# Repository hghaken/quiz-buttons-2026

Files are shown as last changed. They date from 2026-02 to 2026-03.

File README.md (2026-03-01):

# Quiz Buttons 2026

A wireless quiz buzzer system built with **ESP32-S3** hardware buttons and a **Raspberry Pi** web-based game controller.
Players press physical buttons to buzz in; the server tracks press order, manages scores, rounds, jokers, and runs a live web dashboard for the quizmaster.

---

## Table of Contents

- [System Overview](#system-overview)
- [Hardware](#hardware)
  - [Components](#components)
  - [Wiring](#wiring)
- [Software Architecture](#software-architecture)
- [Raspberry Pi Setup](#raspberry-pi-setup)
  - [Dependencies](#dependencies)
  - [Running as a Service](#running-as-a-service)
- [ESP32 Firmware](#esp32-firmware)
  - [PlatformIO Build](#platformio-build)
  - [Configuration](#configuration)
  - [OTA Firmware Updates](#ota-firmware-updates)
- [Network Setup](#network-setup)
- [Game Flow](#game-flow)
- [LED Color Reference](#led-color-reference)
- [Buzzer Patterns](#buzzer-patterns)
- [MQTT Topics](#mqtt-topics)
- [Web Interface](#web-interface)
  - [Results Page](#results-page-http1922)
  - [Score Overview](#score-overview-http1922score)
  - [Setup Page](#setup-page-http1922setup)
- [File Structure](#file-structure)
- [Versioning](#versioning)

---

## System Overview

```
┌─────────────────────────────────────────────────────┐
│              Wi-Fi Network (192.168.0.x)            │
│                                                     │
│  ┌─────────────┐   MQTT    ┌─────────────────────┐  │
│  │  ESP32-S3   │◄─────────►│  Raspberry Pi 4B    │  │
│  │  Button #1  │           │  - Mosquitto MQTT   │  │
│  └─────────────┘           │  - Flask Web Server │  │
│  ┌─────────────┐   MQTT    │  - Python Controller│  │
│  │  ESP32-S3   │◄─────────►│                     │  │
│  │  Button #2  │           │  Port 5000 (HTTP)   │  │
│  └─────────────┘           └──────────┬──────────┘  │
│        ...                            │             │
└───────────────────────────────────────┼─────────────┘
                                        │
                              ┌─────────▼──────────┐
                              │  Quizmaster Browser │
                              │  (any device on LAN)│
                              └────────────────────┘
```

Each ESP32-S3 button connects to the Raspberry Pi via **MQTT** over Wi-Fi.
The Pi runs a **Flask** web server that the quizmaster uses to manage the game.

---

## Hardware

### Components

| Component | Part | Notes |
|---|---|---|
| Microcontroller | Seeed XIAO ESP32-S3 | One per player |
| Button | Momentary push button | Connects D0 (GPIO1) to GND |
| Buzzer | Active buzzer or piezo | Connects D1 (GPIO2) to GND |
| Status LED | Single LED | D2 (GPIO3), MQTT connection indicator |
| RGB LED | Common cathode RGB LED | D8/D9/D10 (GPIO7/8/9) |
| Battery | 3.7V 10000mAh 1260110 Li-ion Polymer Battery | Rechargeable LiPo, one per button |
| Charger / Boost | LX-LCBST TP4056 Module | Li-ion charger + DC-DC step-up boost (3.7V → 5V for ESP32) |
| Server | Raspberry Pi 4B | Runs MQTT broker + Flask |
| Buzzer (Pi) | Active buzzer | GPIO17, confirms quizmaster actions |

### Wiring

#### ESP32-S3 (Seeed XIAO ESP32-S3)

| Pin | GPIO | Function | Resistor |
|---|---|---|---|
| D0 | GPIO 1 | Button (INPUT_PULLUP → GND) | — |
| D1 | GPIO 2 | Active buzzer (→ GND) | 47 Ω |
| D2 | GPIO 3 | Status LED (solid = MQTT connected, flash = disconnected) | 47 Ω |
| D8 | GPIO 7 | RED LED (PWM) | 100 Ω |
| D9 | GPIO 8 | GREEN LED (PWM) | 47 Ω |
| D10 | GPIO 9 | BLUE LED (PWM) | 47 Ω |

#### Raspberry Pi 4B

| GPIO | Function |
|---|---|
| GPIO 17 | Active buzzer (quizmaster feedback) |

### 3D Printed Enclosure

The button housing is designed in **FreeCAD** and printed in 5 parts.
Source and print files are in the [`3D Printer Files/`](3D%20Printer%20Files/) folder.

| File | Description |
|---|---|
| `QuizButton2026.FCStd` | FreeCAD source file (full assembly) |
| `QuizButton2026-PartQB2026MainV3.3mf` | Main body |
| `QuizButton2026-PartQB2026Top.3mf` | Top cover |
| `QuizButton2026-PartQB2026Bottom.3mf` | Bottom plate |
| `QuizButton2026-PartQB2026AccuBracket.3mf` | Battery bracket |
| `QuizButton2026-PartQB2026AccuSupport.3mf` | Battery support |

### ESP32 Power Supply

Each button unit is powered by a LiPo battery with an integrated charger and boost converter:

| Part | Description |
|---|---|
| 3.7V 10000mAh 1260110 Li-ion Polymer Battery | Rechargeable LiPo battery |
| LX-LCBST TP4056 Module | Li-ion charger + DC-DC step-up boost converter (charges via USB, boosts 3.7V → 5V for ESP32) |

#### Battery Life Estimate

| Scenario | Draw | Estimated Runtime |
|---|---|---|
| Peak (WiFi TX bursts) | 125 mA | ~68 hours |
| Average (WiFi idle) | ~70 mA | ~120 hours (~5 days) |

Assumptions: boost converter efficiency 85–90% → usable capacity ≈ 8,500 mAh; LiPo discharged to 3.0V cutoff.
For a typical quiz evening of a few hours, the 10,000 mAh battery will last **dozens of sessions** between charges.

---

## Software Architecture

```
raspberry_pi/
├── server.py                  # Flask + MQTT controller (main application)
├── config.json                # Timeout, rounds, questions per round
├── player_names.json          # Button ID → player/team name mapping
├── scores.json                # Per-round scores per player
├── correct_answers.json       # Correct answer count per round per player
├── jokers.json                # Joker usage per player
├── current_round.json         # Persisted current round number
├── round_descriptions.json    # Round descriptions (e.g. "Music Round")
├── static/
│   └── style.css
└── templates/
    ├── results.html           # Main quizmaster dashboard (auto-refreshes)
    ├── score.html             # Score overview with chart
    ├── setup.html             # Game configuration + OTA
    └── restart.html           # Shown during server restart

src/
└── main.cpp                   # ESP32-S3 Arduino firmware (PlatformIO)

platformio.ini                 # PlatformIO build configuration
```

---

## Raspberry Pi Setup

### Dependencies

```bash
sudo apt update && sudo apt install -y mosquitto mosquitto-clients python3-pip python3-venv

# Create virtual environment
python3 -m venv /home/game/quiz/env
source /home/game/quiz/env/bin/activate

pip install flask paho-mqtt gpiozero matplotlib
```

### Deploy Files

```bash
# Copy project files to Pi
scp -P 2222 -r raspberry_pi/* game@<pi-ip>:/home/game/quiz/
```

### Running as a Service

Create `/etc/systemd/system/quiz.service`:

```ini
[Unit]
Description=Quiz Server
After=network.target mosquitto.service

[Service]
User=game
WorkingDirectory=/home/game/quiz
ExecStart=/home/game/quiz/env/bin/python3 /home/game/quiz/server.py
Restart=on-failure

[Install]
WantedBy=multi-user.target
```

```bash
sudo systemctl enable quiz
sudo systemctl start quiz
sudo systemctl status quiz
```

### Mosquitto MQTT Broker

The MQTT broker runs locally on the Pi on port `1883`.
The ESP32 buttons connect using credentials:

```
Username: quizuser
Password: quizpass
```

Configure `/etc/mosquitto/mosquitto.conf` to allow these credentials.

---

## ESP32 Firmware

### PlatformIO Build

```bash
# Install PlatformIO (VS Code extension or CLI)
pio run                        # Build
pio run --target upload        # Flash via USB (COM4)
```

Board: `seeed_xiao_esp32s3`
Framework: Arduino
Library: `knolleary/PubSubClient@^2.8`

### Configuration

Edit the constants at the top of [src/main.cpp](src/main.cpp):

```cpp
const char* version    = "v0.13 (01-03-2026)";
const char* ssid       = "your-wifi-ssid";
const char* password   = "your-wifi-password";
const char* mqttServer = "192.168.0.10";   // Raspberry Pi IP
const int   mqttPort   = 1883;
const char* mqttUser   = "quizuser";
const char* mqttPass   = "quizpass";
```

### OTA Firmware Updates

The ESP32 supports **HTTP pull-based OTA** — the device downloads firmware from the Pi's Flask server when triggered via MQTT.

**Process:**
1. Build the firmware: `pio run`
2. Copy `.pio/build/seeed_xiao_esp32s3/firmware.bin` to the project
3. Upload via the Setup page → **"Uploaden naar Pi"**
4. Click **"OTA Update — Alle Knoppen"** (all buttons) or per-button OTA
5. Buttons turn **purple** (downloading) → **green** (done) → reboot

The firmware binary is served at `http://<pi-ip>:5000/firmware.bin`.

---

## Network Setup

| Device | IP Address | Notes |
|---|---|---|
| Raspberry Pi 4B | `192.168.0.10` | MQTT broker + Flask server |
| ESP32 Buttons | `192.168.0.x` | DHCP, same subnet as Pi |
| Quizmaster PC | `10.10.8.x` | Different subnet, accesses Pi via port 5000 |

> The ESP32 buttons are on a dedicated `192.168.0.0/24` network. OTA uses HTTP pull from the Pi so the buttons can reach the server even when the quizmaster's PC cannot directly reach the buttons.

---

## Game Flow

```
Server start → Round 1, Question 1
     │
     ▼
[Joker phase] ← Only at round start, before first question
     │           Each player may use their joker once (doubles points for that round)
     ▼
"Start Vraag" (Blue button) → All buttons ENABLED (green LED)
     │
     ▼
Players press buttons → Press order recorded
     │                   Rank colors assigned (Blue=1st, Purple=2nd, Yellow=3rd, White=rest)
     ▼
Countdown timer starts (configurable, default 30s)
     │
     ▼
1st player answers:
  ├── Correct → Award 1/2/3 points → "Volgende Vraag" / "Volgende Ronde"
  └── Wrong   → "Fout (Blokeren)" → 2nd player answers → ...
                                          └── All wrong → "Reset Ronde (geen punten)"
                                                          (wrong-answer buttons stay red,
                                                           unanswered buttons re-enabled)
     │
     ▼
After all questions in round → "Volgende Ronde" (cyan button)
     │
     ▼
After all rounds → "Quiz compleet!"
```

---

## LED Color Reference

### RGB LED (game state)

| Color | Meaning |
|---|---|
| Green | Button enabled / waiting for question |
| Red | Button disabled / locked |
| Blue | Rank 1 (buzzed in first) |
| Purple | Rank 2 (buzzed in second) |
| Yellow | Rank 3 (buzzed in third) |
| White | Rank 4+ (buzzed in but not top 3) |
| Purple | OTA firmware downloading |

**Startup sequence:**
Green (init) → Red (WiFi connected) → White (NTP synced) → Blue (MQTT ready) + 1s beep

### Status LED (D2 / GPIO3)

| State | Meaning |
|---|---|
| Solid ON | MQTT connected |
| Flashing (500ms) | MQTT disconnected, retrying every 5 s |

---

## Buzzer Patterns

| Pattern | Beeps | Trigger |
|---|---|---|
| PAT_ANSWER | 1 beep (200ms) | Your buzz acknowledged |
| PAT_RESET | 2 beeps (150ms each) | Round reset / button unlocked |
| PAT_DISABLE | 3 beeps (130ms each) | Button locked / disabled |

---

## MQTT Topics

| Topic | Direction | Payload | Description |
|---|---|---|---|
| `quiz/all` | Pi → Buttons | `enable`, `disable`, `lock`, `unlock`, `reset`, `reregister`, `ota`, `brightness:R,G,B` | Broadcast command to all buttons |
| `quiz/<id>` | Pi → Button | `enable`, `disable`, `buzz`, `rank:1`…`rank:4`, `ota` | Command to specific button |
| `quiz/register` | Button → Pi | `<button-id>` | Button announces itself on connect |
| `quiz/version` | Button → Pi | `<id>,<version>,<ip>` | Firmware version + IP report |
| `quiz/press` | Button → Pi | `<id>,<timestamp-ms>` | Button press event |
| `quiz/heartbeat` | Button → Pi | `<button-id>` | Keep-alive every 5 seconds |
| `quiz/offline` | Button → Pi (LWT) | `<button-id>` | Last-will message on disconnect |

Button IDs are the ESP32 MAC address formatted as a 16-character uppercase hex string.

---

## Web Interface

### Results Page (`http://<pi-ip>:5000/`)

The main quizmaster dashboard. Auto-refreshes every 2 seconds.

- Shows all registered buttons sorted by name (then by press order during a question)
- Displays press rank, speed (ms relative to first press), status, score, correct answers, joker
- Buttons: Start Question, Next Question, Next Round, Award Points (1/2/3), Block Wrong Answer, Reset Round, Reset Scores, Find All Buttons
- Countdown timer during answer phase

### Score Overview (`http://<pi-ip>:5000/score`)

- Sortable score table with per-round breakdown (points + correct answers)
- Cumulative score graph per round (matplotlib PNG)
- Joker usage shown per player

### Setup Page (`http://<pi-ip>:5000/setup`)

| Section | Setting |
|---|---|
| 1 | Answer timeout in seconds (0 = disabled) |
| 2 | Total number of rounds |
| 3 | Number of questions per round |
| 4 | Round descriptions (e.g. "Music Round", "General Knowledge") |
| 5 | Player / team names and display colors per button |
| 6 | RGB LED brightness (separate R/G/B sliders, 0–255) |
| 7 | OTA firmware update (upload .bin + trigger update per button or all) |

Also: Restart server, Shutdown Pi, software version display.

---

## File Structure

```
Quiz Buttons 2026/
├── 3D Printer Files/
│   ├── QuizButton2026.FCStd      # FreeCAD source (full assembly)
│   ├── QuizButton2026-PartQB2026MainV3.3mf
│   ├── QuizButton2026-PartQB2026Top.3mf
│   ├── QuizButton2026-PartQB2026Bottom.3mf
│   ├── QuizButton2026-PartQB2026AccuBracket.3mf
│   └── QuizButton2026-PartQB2026AccuSupport.3mf
├── src/
│   └── main.cpp                  # ESP32-S3 Arduino firmware
├── raspberry_pi/
│   ├── server.py                 # Flask + MQTT quiz controller
│   ├── config.json               # Game settings
│   ├── player_names.json         # Button → name mapping
│   ├── player_colors.json        # Button → display color mapping
│   ├── scores.json               # Score data
│   ├── correct_answers.json      # Correct answer counts
│   ├── jokers.json               # Joker usage
│   ├── current_round.json        # Current round state
│   ├── round_descriptions.json   # Round labels
│   ├── led_brightness.json       # RGB LED brightness per channel
│   ├── static/
│   │   └── style.css
│   └── templates/
│       ├── results.html
│       ├── score.html
│       ├── setup.html
│       └── restart.html
├── platformio.ini                # PlatformIO config (seeed_xiao_esp32s3)
├── ...AI Info/
│   ├── Game rules.txt            # Game rules and flow description
│   └── OTA Upload Info.txt       # OTA setup notes
└── README.md
```

---

## Versioning

| Component | Version | File |
|---|---|---|
| ESP32 Firmware | v0.13 (01-03-2026) | `src/main.cpp` |
| Quiz Server | v1.0.5 (01-03-2026) | `raspberry_pi/server.py` |

Server version is displayed in the bottom-right corner of the Setup page.
Per-button firmware version is reported via MQTT on connect and shown in the OTA table on the Setup page.

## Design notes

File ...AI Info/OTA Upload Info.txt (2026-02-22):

When you update the firmware:

1 - Make code changes in VS Code

2 - Build: pio run (or press the PlatformIO build button) (check icon in bottom)
    generates: .pio/build/seeed_xiao_esp32s3/firmware.bin

3 - Go to the Setup page → section 5. OTA Firmware Update

4 - Click "Selecteer firmware .bin bestand" → browse to
    .pio/build/seeed_xiao_esp32s3/firmware.bin

5 - Click "Uploaden naar Pi" — uploads the binary to the Pi
    /home/game/quiz/firmware.bin

6 - Click "OTA Update — Alle Knoppen" — Pi sends MQTT ota to all buttons

7 - Buttons turn purple (downloading), then green (done) and reboot automatically

No USB cable, no IP addresses to remember, no terminal commands needed.

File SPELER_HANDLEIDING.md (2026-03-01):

# Quiz Knop — Speler Handleiding

---

## Jouw knop

Elke speler heeft een draadloze quiz-knop met:

- Een grote **drukknop** bovenop
- Een **RGB LED** die aangeeft wat de status van jouw knop is
- Een **zoemer** die geluid geeft bij belangrijke momenten
- Een **oplaadbare batterij** (USB-C aansluiting)

---

## LED Kleuren

De kleur van het lampje vertelt je precies wat er aan de hand is.

| Kleur | Betekenis |
|---|---|
| 🟢 **Groen** | Knop is actief — je kunt buzzen! |
| 🔴 **Rood** | Knop is uitgeschakeld — wachten |
| 🔵 **Blauw** | Jij was de **eerste** die drukte |
| 🟣 **Paars** | Jij was de **tweede** die drukte |
| 🟡 **Geel** | Jij was de **derde** die drukte |
| ⚪ **Wit** | Jij drukte ook, maar later (4e of verder) |

> **Tip:** Hoe eerder je drukt, hoe eerder je mag antwoorden!

---

## Zoemer Signalen

De zoemer in de knop geeft je feedback:

| Signaal | Betekenis |
|---|---|
| **1 korte piep** | Je buzz is geregistreerd |
| **2 piepen** | De ronde is gereset — knop weer actief |
| **3 piepen** | Jouw knop is uitgeschakeld (fout antwoord) |

---

## Hoe werkt het spel?

### Stap 1 — Wachten op de vraag
De quizmaster stelt de vraag. Jouw LED is **rood** — nog niet drukken.

### Stap 2 — Knop groen!
Zodra de LED **groen** wordt, mag je buzzen. Weet je het antwoord? **Druk de knop!**

### Stap 3 — Buzz geregistreerd
Je hoort **1 piep** en je LED toont jouw rangkleur:
- Blauw = jij was 1e, Paars = 2e, Geel = 3e, Wit = 4e of later

### Stap 4 — Antwoorden
De **eerste** speler (blauwe LED) geeft het antwoord.

**Antwoord goed?** → De quizmaster geeft punten. De ronde is klaar.

**Antwoord fout?** → Jouw knop wordt rood (3 piepen). De **volgende** speler in de rij mag antwoorden.

### Stap 5 — Niemand weet het
Als niemand het goed heeft, resettet de quizmaster de ronde. Je hoort **2 piepen** en je LED wordt weer groen — alle knoppen gaan een nieuwe vraag in.

> **Let op:** Spelers met een fout antwoord blijven rood — zij mogen bij de volgende vraag gewoon weer meedoen.

---

## Punten

De quizmaster kent punten toe: **1**, **2** of **3** punten per vraag.
Hoeveel punten je krijgt hangt af van de moeilijkheid van de vraag.

Jouw score is live te zien op het scorebord.

---

## De Joker 🃏

Elke speler heeft **één joker** voor het hele spel.

- De joker verdubbelt al jouw punten voor een **hele ronde**
- Je kunt de joker alleen inzetten **vóór de eerste vraag** van een ronde
- Gebruik hem slim — wanneer jij denkt dat je het goed doet!

> **Voorbeeld:** Je joker inzetten in de muziekronde als je veel van muziek weet = extra beloning voor elk goed antwoord in die ronde.

---

## Opstarten

Wanneer de knop wordt aangezet doorloopt hij een korte reeks:

| LED kleur | Wat er gebeurt |
|---|---|
| 🟢 Groen | Knop start op |
| 🔴 Rood | Verbinding met WiFi gemaakt |
| ⚪ Wit | Tijd wordt gesynchroniseerd |
| 🔵 Blauw + lange piep | Verbonden met de quiz server — klaar! |

De knop staat klaar zodra je de lange piep hoort.

---

## Tips

- **Druk alleen als je het antwoord weet** — een fout antwoord blokkeert jou en geeft anderen de kans.
- **Wacht op groen** — te vroeg drukken werkt niet (knop is nog rood).
- **Joker op het juiste moment** — gebruik hem in de ronde waar jij het sterkst bent.
- **Knop valt uit?** Vraag de quizmaster om "Alle knoppen zoeken" te klikken. Jouw knop meldt zich vanzelf opnieuw aan.

---

## Opladen

- Laad de knop op via de **USB-C** aansluiting.
- De batterij is groot genoeg voor meerdere speelrondes — maar laad op na gebruik.
- Laad **niet** op terwijl de knop in het spel is.

---

*Veel plezier en veel succes!* 🎉

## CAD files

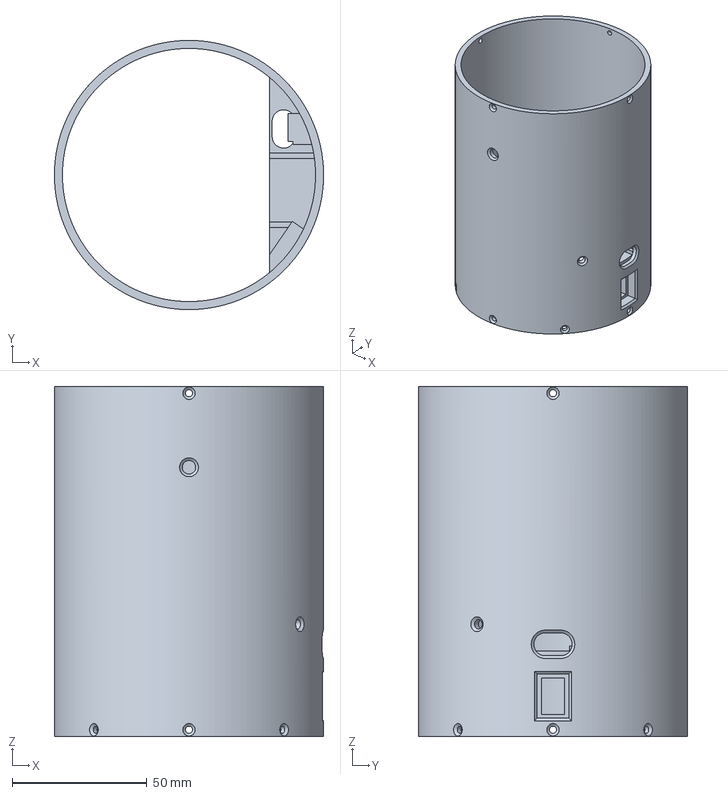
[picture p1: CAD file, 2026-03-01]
3D Printer Files/QuizButton2026-PartQB2026MainV3.3mf
100.0 x 100.0 x 130.0 mm

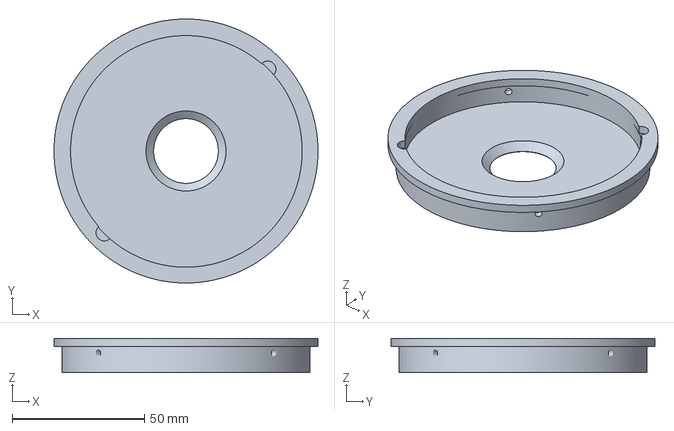
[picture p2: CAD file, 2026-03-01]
3D Printer Files/QuizButton2026-PartQB2026Top.3mf
100.0 x 100.0 x 13.0 mm

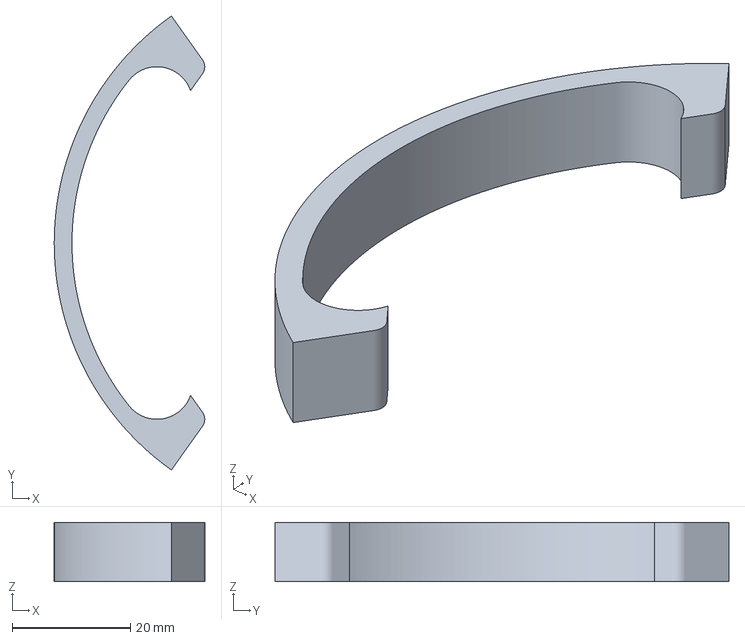
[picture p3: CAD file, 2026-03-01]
3D Printer Files/QuizButton2026-PartQB2026AccuBracket.3mf
25.4 x 76.6 x 10.0 mm

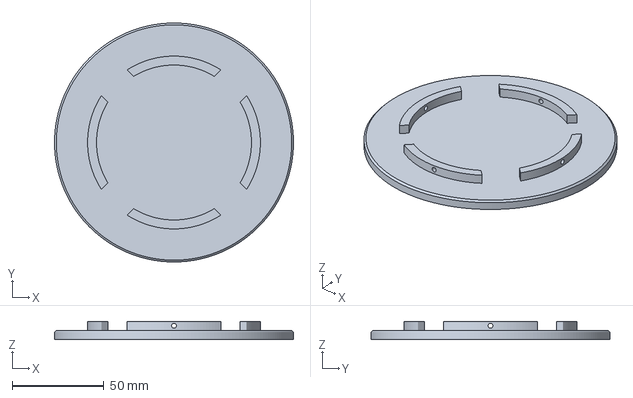
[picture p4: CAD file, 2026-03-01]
3D Printer Files/QuizButton2026-PartQB2026Bottom.3mf
130.0 x 130.0 x 9.80 mm

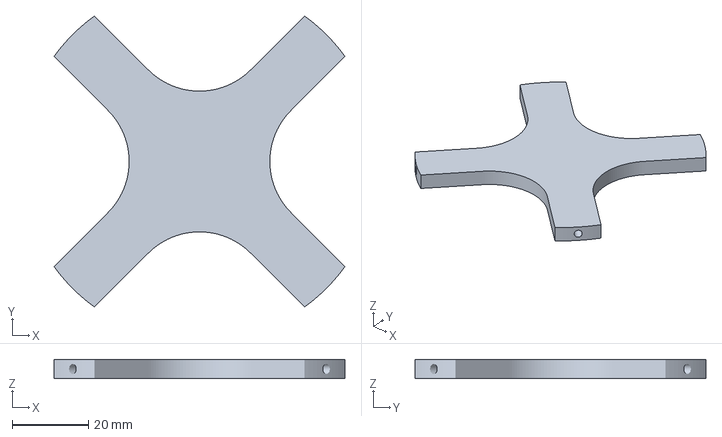
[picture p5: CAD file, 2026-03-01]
3D Printer Files/QuizButton2026-PartQB2026AccuSupport.3mf
76.2 x 76.2 x 5.00 mm

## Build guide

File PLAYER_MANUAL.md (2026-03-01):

# Quiz Button — Player Manual

---

## Your Button

Every player has a wireless quiz button with:

- A large **push button** on top
- An **RGB LED** that shows the status of your button
- A **buzzer** that gives audio feedback at key moments
- A **rechargeable battery** (USB-C connector)

---

## LED Colors

The color of the LED tells you exactly what is happening.

| Color | Meaning |
|---|---|
| 🟢 **Green** | Button is active — you can buzz! |
| 🔴 **Red** | Button is disabled — wait |
| 🔵 **Blue** | You were the **first** to press |
| 🟣 **Purple** | You were the **second** to press |
| 🟡 **Yellow** | You were the **third** to press |
| ⚪ **White** | You pressed too, but later (4th or beyond) |

> **Tip:** The earlier you press, the earlier you get to answer!

---

## Buzzer Signals

The buzzer inside the button gives you audio feedback:

| Signal | Meaning |
|---|---|
| **1 short beep** | Your buzz has been registered |
| **2 beeps** | The round was reset — button is active again |
| **3 beeps** | Your button has been disabled (wrong answer) |

---

## How Does the Game Work?

### Step 1 — Wait for the question
The quizmaster reads the question. Your LED is **red** — do not press yet.

### Step 2 — Button turns green!
As soon as the LED turns **green**, you may buzz in. Know the answer? **Press the button!**

### Step 3 — Buzz registered
You hear **1 beep** and your LED shows your rank color:
- Blue = you were 1st, Purple = 2nd, Yellow = 3rd, White = 4th or later

### Step 4 — Answer the question
The **first** player (blue LED) gives their answer.

**Answer correct?** → The quizmaster awards points. The question is done.

**Answer wrong?** → Your button turns red (3 beeps). The **next** player in line gets to answer.

### Step 5 — Nobody knows it
If nobody answers correctly, the quizmaster resets the round. You hear **2 beeps** and your LED turns green again — all buttons are ready for the next question.

> **Note:** Players who gave a wrong answer stay red for that question, but can buzz in again on the next question.

---

## Points

The quizmaster awards **1**, **2** or **3** points per question.
The number of points depends on the difficulty of the question.

Your score is shown live on the scoreboard.

---

## The Joker 🃏

Every player has **one joker** for the entire game.

- The joker **doubles all your points** for an entire round
- You can only use the joker **before the first question** of a round
- Use it wisely — pick the round where you think you will score best!

> **Example:** Using your joker in the music round when you know a lot about music = extra reward for every correct answer in that round.

---

## Startup Sequence

When the button is switched on it runs through a short sequence:

| LED Color | What is happening |
|---|---|
| 🟢 Green | Button is starting up |
| 🔴 Red | Connected to WiFi |
| ⚪ White | Time is being synchronized |
| 🔵 Blue + long beep | Connected to the quiz server — ready! |

The button is ready to use as soon as you hear the long beep.

---

## Tips

- **Only press if you know the answer** — a wrong answer blocks you and gives others a chance.
- **Wait for green** — pressing too early does nothing (button is still red).
- **Joker timing matters** — use it in the round where you are strongest.
- **Button disconnected?** Ask the quizmaster to click "Find all buttons". Your button will automatically reconnect.

---

## Charging

- Charge the button using the **USB-C** connector.
- The battery is large enough for multiple game sessions — but charge it after use.
- Do **not** charge while the button is actively in a game.

---

*Good luck and have fun!* 🎉

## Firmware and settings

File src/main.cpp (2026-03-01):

// RGB LED states:
// setup():
//   GREEN   – Initialising
//   RED     – WiFi connected
//   WHITE   – NTP time synced
//   BLUE    – MQTT connected and ready  + long buzz
// loop():
//   GREEN   – Button enabled / unlocked
//   RED     – Button disabled / locked
//   BLUE    – Rank 1 (winner)
//   PURPLE  – Rank 2  (180,0,180 – distinct from OTA violet 128,0,255)
//   YELLOW  – Rank 3
//   WHITE   – Rank 4+
//   PURPLE  – OTA firmware downloading
//   GREEN   – OTA done → reboot
//   RED     – OTA error
//
// Status LED (D2):
//   ON      – MQTT connected
//   FLASH   – MQTT disconnected (retrying every 5 s)

#include <Arduino.h>
#include <WiFi.h>
#include <PubSubClient.h>
#include <HTTPClient.h>
#include <Update.h>
#include <esp_mac.h>  // For ESP.getEfuseMac()
#include <time.h>     // For NTP sync

#define BUTTON_PIN     1  // D0 GPIO 1 Momentary switch, connect to GND (internal pull-up)
#define BUZZER_PIN     2  // D1 GPIO 2 Active buzzer or piezo, connect to GND
#define STATUS_LED_PIN 3  // D2 GPIO 3 Connection status LED (solid=connected, flash=disconnected)

#define RED_PIN   7   // D8  GPIO 7 PWM pin for RED LED
#define GREEN_PIN 8   // D9  GPIO 8 PWM pin for GREEN LED
#define BLUE_PIN  9   // D10 GPIO 9 PWM pin for BLUE LED

const char* version    = "v0.13 (01-03-2026)";
const char* ssid       = "gamecontroller2.4";
const char* password   = "gamecontroller";
const char* mqttServer = "192.168.0.10";       // MQTT Controller IP address RPI 4B
const int   mqttPort   = 1883;                 // Default MQTT port
const char* mqttUser   = "quizuser";           // MQTT username
const char* mqttPass   = "quizpass";           // MQTT password
const unsigned long hbInterval  = 5000;        // Heartbeat interval in ms
const int           keepAlive   = 3;           // MQTT keep-alive in seconds
const int           deBounceVal = 400;         // Button debounce in ms

// NTP settings
const char* ntpServer1        = "nl.pool.ntp.org";
const char* ntpServer2        = "time.nist.gov";
long        gmtOffset_sec     = 3600;          // UTC+1; adjust for timezone
int         daylightOffset_sec = 0;

// MQTT client and topics
WiFiClient   espClient;
PubSubClient client(espClient);

String myId;
String allTopic;
String myTopic;

bool          enabled         = false;  // Button starts disabled
bool          rankActive      = false;  // Suppress green/red override while rank color is shown
unsigned long lastHeartbeat   = 0;
unsigned long lastReconnectMs = 0;
unsigned long lastPress       = 0;
unsigned long blinkMs         = 0;
bool          blinkState      = false;


// ── LED (cached – skip PWM write when color is unchanged) ────────────────────

bool    ledReady = false;
uint8_t ledR, ledG, ledB;
float   brightnessR = 1.0f;   // Per-channel brightness scale (0.0 – 1.0)
float   brightnessG = 1.0f;
float   brightnessB = 1.0f;

void setColor(uint8_t r, uint8_t g, uint8_t b) {
  if (ledReady && r == ledR && g == ledG && b == ledB) return;
  ledR = r; ledG = g; ledB = b; ledReady = true;
  ledcWrite(0, (uint8_t)(r * brightnessR));  // channel 0 = RED_PIN
  ledcWrite(1, (uint8_t)(g * brightnessG));  // channel 1 = GREEN_PIN
  ledcWrite(2, (uint8_t)(b * brightnessB));  // channel 2 = BLUE_PIN
}


// ── BUZZER (non-blocking state machine) ──────────────────────────────────────
//
// Each pattern: alternating ON/OFF durations (ms), terminated by 0.
// Even indices (0,2,4…) = buzzer ON; odd indices = buzzer OFF.
//
//   PAT_ANSWER  {200, 0}                → 1 beep
//   PAT_RESET   {150, 150, 150, 0}      → 2 beeps
//   PAT_DISABLE {130,130,130,130,130,0} → 3 beeps

static const uint16_t PAT_ANSWER[]  = {200, 0};
static const uint16_t PAT_RESET[]   = {150, 150, 150, 0};
static const uint16_t PAT_DISABLE[] = {130, 130, 130, 130, 130, 0};

const uint16_t* buzPat  = nullptr;
int             buzStep = 0;
unsigned long   buzMs   = 0;

// ── Start Buzzer On ───────────────────────────
void startBuzz(const uint16_t* pat) {
  buzPat  = pat;
  buzStep = 0;
  buzMs   = millis();
  digitalWrite(BUZZER_PIN, HIGH);
}


// ── Update Buzzer (Non Blocking) ───────────────────────────
void updateBuzzer() {
  if (!buzPat) return;
  if (millis() - buzMs < (unsigned long)buzPat[buzStep]) return;

  buzStep++;
  buzMs = millis();

  if (buzPat[buzStep] == 0) {
    digitalWrite(BUZZER_PIN, LOW);
    buzPat = nullptr;
    return;
  }
  // Even step = ON, odd step = OFF
  digitalWrite(BUZZER_PIN, (buzStep % 2 == 0) ? HIGH : LOW);
}


// ── HTTP OTA (blocking – called from MQTT callback) ───────────────────────────
void performOTA() {
  client.disconnect();           // Clean MQTT disconnect before flashing
  buzPat = nullptr;              // Stop any active buzzer pattern
  digitalWrite(BUZZER_PIN, LOW);
  setColor(128, 0, 255);         // Purple: downloading

  String url = String("http://") + mqttServer + ":5000/firmware.bin";
  Serial.println("OTA: " + url);

  HTTPClient http;
  http.begin(url);
  int code = http.GET();

  if (code == 200) {
    int len = http.getSize();
    if (len <= 0) {
      Serial.println("OTA: no content-length");
      setColor(255, 0, 0);
      http.end();
      return;
    }
    WiFiClient* stream = http.getStreamPtr();
    if (Update.begin(len)) {
      if (Update.writeStream(*stream) == (size_t)len && Update.end(true)) {
        setColor(0, 255, 0);     // Green: done, rebooting
        http.end();
        delay(500);
        ESP.restart();
      } else {
        Update.printError(Serial);
        setColor(255, 0, 0);     // Red: flash error
      }
    } else {
      Update.printError(Serial);
      setColor(255, 0, 0);       // Red: not enough space
    }
  } else {
    Serial.println("OTA HTTP error: " + String(code));
    setColor(255, 0, 0);         // Red: server error
  }
  http.end();
}


// ── MQTT CALLBACK ─────────────────────────────────────────────────────────────
void callback(char* topic, byte* payload, unsigned int length) {
  // Pre-allocate to avoid String reallocation during append
  String msg;
  msg.reserve(length);
  for (unsigned int i = 0; i < length; i++) msg += (char)payload[i];

  // strcmp avoids heap allocation from constructing String(topic) on each call
  if (strcmp(topic, allTopic.c_str()) == 0) {
    if (msg == "reset") {
      digitalWrite(BUZZER_PIN, HIGH); delay(200); digitalWrite(BUZZER_PIN, LOW);
      delay(100);
      ESP.restart();                  // Full reboot – same sequence as power-on
    } else if (msg == "reregister") {
      client.publish("quiz/register", myId.c_str());
      client.publish("quiz/version",  (myId + "," + String(version) + "," + WiFi.localIP().toString()).c_str());
    } else if (msg == "lock") {
      enabled = false;
      if (!rankActive) setColor(255, 0, 0);  // Red: locked (skip if rank color active)
      startBuzz(PAT_DISABLE);                // 3 beeps
    } else if (msg == "unlock") {
      rankActive = false;
      enabled = true;
      setColor(0, 255, 0);            // Green: unlocked
      startBuzz(PAT_RESET);           // 2 beeps
    } else if (msg == "ota") {
      performOTA();
    } else if (msg.startsWith("brightness:")) {
      String vals = msg.substring(11);
      int c1 = vals.indexOf(',');
      int c2 = vals.indexOf(',', c1 + 1);
      brightnessR = vals.substring(0, c1).toInt()       / 255.0f;
      brightnessG = vals.substring(c1 + 1, c2).toInt()  / 255.0f;
      brightnessB = vals.substring(c2 + 1).toInt()      / 255.0f;
      ledReady = false;  // Invalidate cache so setColor re-writes with new brightness
      setColor(ledR, ledG, ledB);
    }

  } else if (strcmp(topic, myTopic.c_str()) == 0) {
    if (msg == "buzz") {
      startBuzz(PAT_ANSWER);          // 1 beep
    } else if (msg == "disable") {
      rankActive = false;            // Always override rank color on explicit disable
      enabled = false;
      setColor(255, 0, 0);           // Red: disabled
      startBuzz(PAT_DISABLE);        // 3 beeps
    } else if (msg == "enable") {
      rankActive = false;
      enabled = true;
      setColor(0, 255, 0);            // Green: enabled
      startBuzz(PAT_RESET);           // 2 beeps
    } else if (msg == "ota") {
      performOTA();
    } else if (msg.startsWith("rank:")) {
      rankActive = true;              // Hold rank color until next enable/disable
      int rank = msg.substring(5).toInt();
      if      (rank == 1) setColor(0,   0,   255); // Blue   – rank 1
      else if (rank == 2) setColor(180,   0, 180); // Purple – rank 2
      else if (rank == 3) setColor(255, 255, 0);   // Yellow – rank 3
      else                setColor(255, 255, 255); // White  – rank > 3
    }
  }
}


// ── MQTT CONNECT (non-blocking helper) ────────────────────────────────────────
bool mqttConnect() {
  if (client.connect(myId.c_str(), "quiz/offline", 1, false, myId.c_str())) {
    client.subscribe(allTopic.c_str());
    client.subscribe(myTopic.c_str());
    client.publish("quiz/register", myId.c_str());
    client.publish("quiz/version",  (myId + "," + String(version) + "," + WiFi.localIP().toString()).c_str());
    setColor(0, 0, 255);  // Blue: connected
    digitalWrite(STATUS_LED_PIN, HIGH);  // Solid: connected
    return true;
  }
  return false;
}


// ── HELPERS ───────────────────────────────────────────────────────────────────
String getUniqueId() {
  uint64_t mac = ESP.getEfuseMac();
  char id[17];
  sprintf(id, "%016llX", mac);
  return String(id);  // ESP32 MAC address as unique ID
}


// ── SETUP ─────────────────────────────────────────────────────────────────────
void setup() {
  Serial.begin(115200);

  pinMode(BUTTON_PIN, INPUT_PULLUP);
  pinMode(BUZZER_PIN, OUTPUT);
  digitalWrite(BUZZER_PIN, LOW);
  pinMode(STATUS_LED_PIN, OUTPUT);
  digitalWrite(STATUS_LED_PIN, LOW);

  ledcSetup(0, 5000, 8); ledcAttachPin(RED_PIN,   0);  // channel 0 → RED
  ledcSetup(1, 5000, 8); ledcAttachPin(GREEN_PIN, 1);  // channel 1 → GREEN
  ledcSetup(2, 5000, 8); ledcAttachPin(BLUE_PIN,  2);  // channel 2 → BLUE

  // Init chirp + green
  digitalWrite(BUZZER_PIN, HIGH); delay(1); digitalWrite(BUZZER_PIN, LOW);
  setColor(0, 255, 0);  // Green: initialising
  delay(3000);

  myId     = getUniqueId();
  allTopic = "quiz/all";
  myTopic  = "quiz/" + myId;

  Serial.println("\n\n\n\n\n\n===================================");
  Serial.println("Firmware: " + String(version));
  Serial.println("ID:       " + myId);

  // WiFi – setAutoReconnect handles WiFi drops automatically
  WiFi.mode(WIFI_STA);
  WiFi.setAutoReconnect(true);
  WiFi.setSleep(false);
  WiFi.begin(ssid, password);
  Serial.print("WiFi connecting to: " + String(ssid));
  while (WiFi.status() != WL_CONNECTED) { delay(500); Serial.print("."); }
  Serial.println("\nIP: " + WiFi.localIP().toString());
  setColor(255, 0, 0);  // Red: WiFi connected
  delay(3000);

  // NTP time sync
  configTime(gmtOffset_sec, daylightOffset_sec, ntpServer1, ntpServer2);
  struct tm timeinfo;
  Serial.print("NTP sync");
  while (!getLocalTime(&timeinfo)) { delay(500); Serial.print("."); }
  char buf[50];
  strftime(buf, sizeof(buf), "%A, %d %B %Y - %H:%M:%S", &timeinfo);
  Serial.println("\nTime: " + String(buf));
  setColor(255, 255, 255);  // White: time synced
  delay(3000);

  // MQTT – setKeepAlive once here, not inside the reconnect loop
  client.setServer(mqttServer, mqttPort);
  client.setKeepAlive(keepAlive);
  client.setCallback(callback);
  mqttConnect();  // Initial connect (blocking is fine in setup)

  // Ready beep (blocking delay is fine in setup)
  digitalWrite(BUZZER_PIN, HIGH); delay(1000); digitalWrite(BUZZER_PIN, LOW);
}


// ── MAIN LOOP ─────────────────────────────────────────────────────────────────
void loop() {
  updateBuzzer();  // Drive non-blocking buzzer state machine
  client.loop();

  if (!client.connected()) {
    // Flash status LED while disconnected
    if (millis() - blinkMs >= 500) {
      blinkMs    = millis();
      blinkState = !blinkState;
      digitalWrite(STATUS_LED_PIN, blinkState ? HIGH : LOW);
    }
    // Retry MQTT every 5 s – non-blocking, device stays fully responsive
    if (millis() - lastReconnectMs >= 5000) {
      lastReconnectMs = millis();
      mqttConnect();
    }
    return;  // Skip button/heartbeat while offline
  }

  // LED reflects button state – held on rank color until next enable/disable
  if (!rankActive) {
    setColor(enabled ? 0 : 255, enabled ? 255 : 0, 0);  // Green=enabled / Red=disabled
  }

  // Heartbeat
  if (millis() - lastHeartbeat >= hbInterval) {
    lastHeartbeat = millis();
    client.publish("quiz/heartbeat", myId.c_str());
  }

  // Button press
  if (enabled && digitalRead(BUTTON_PIN) == LOW && millis() - lastPress > (unsigned long)deBounceVal) {
    lastPress = millis();

    // Timestamp: prefer NTP unix time (ms), fall back to millis()
    unsigned long long pressTime;
    struct tm timeinfo;
    pressTime = getLocalTime(&timeinfo)
                  ? (unsigned long long)time(NULL) * 1000ULL
                  : (unsigned long long)millis();

    char pressStr[20];
    sprintf(pressStr, "%llu", pressTime);
    String payload = myId + "," + pressStr;

    if (client.publish("quiz/press", payload.c_str())) {
      enabled = false;  // Lock until reset/enable from server
    }
  }
}

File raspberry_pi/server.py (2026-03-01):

import paho.mqtt.client as mqtt
import threading
import time
import json
import os
from flask import Flask, render_template, request, redirect, url_for, send_file
from gpiozero import OutputDevice
import statistics
from paho.mqtt.client import CallbackAPIVersion
import matplotlib.pyplot as plt
import io
import base64

# =========================================================================== VERSIE & CONFIG =====
VERSION = "v1.0.5 (01-03-2026)"
BUZZER_PIN = 17

# Bestandspaden
CONFIG_FILE          = '/home/game/quiz/config.json'
PLAYER_NAMES_FILE    = '/home/game/quiz/player_names.json'
PLAYER_COLORS_FILE   = '/home/game/quiz/player_colors.json'
SCORES_FILE          = '/home/game/quiz/scores.json'
CURRENT_ROUND_FILE   = '/home/game/quiz/current_round.json'
ROUND_DESC_FILE      = '/home/game/quiz/round_descriptions.json'
JOKERS_FILE          = '/home/game/quiz/jokers.json'
CORRECT_ANSWERS_FILE = '/home/game/quiz/correct_answers.json'
LED_BRIGHTNESS_FILE  = '/home/game/quiz/led_brightness.json'
LANG_DIR             = os.path.join(os.path.dirname(os.path.abspath(__file__)), 'lang')


# =========================================================================== BESTAND HELPERS =====
def load_json(filepath, default):
    """Load a JSON file, return default if it doesn't exist."""
    if os.path.exists(filepath):
        with open(filepath, 'r') as f:
            return json.load(f)
    return default

def save_json(filepath, data):
    """Save data to a JSON file."""
    with open(filepath, 'w') as f:
        json.dump(data, f)


# =========================================================================== DATA LADEN =====
config             = load_json(CONFIG_FILE, {})

# =========================================================================== TAAL =====
lang_strings = {}

def load_language(code):
    global lang_strings
    path = os.path.join(LANG_DIR, f'{code}.json')
    with open(path, 'r', encoding='utf-8') as f:
        lang_strings = json.load(f)

load_language(config.get('language', 'nl'))

player_names       = load_json(PLAYER_NAMES_FILE, {})
player_colors      = load_json(PLAYER_COLORS_FILE, {})
led_brightness     = load_json(LED_BRIGHTNESS_FILE, {'r': 255, 'g': 255, 'b': 255})
scores             = load_json(SCORES_FILE, {})
round_descriptions = load_json(ROUND_DESC_FILE, {})
correct_answers    = load_json(CORRECT_ANSWERS_FILE, {})
jokers             = load_json(JOKERS_FILE, {})

ANSWER_TIMEOUT      = config.get('answer_timeout', 30)
TOTAL_ROUNDS        = config.get('total_rounds', 10)
QUESTIONS_PER_ROUND = config.get('questions_per_round', 10)

try:
    current_round = load_json(CURRENT_ROUND_FILE, {}).get('current_round', 1)
    print(f"Loaded current round: {current_round}")
except Exception:
    current_round = 1
    print("No current_round.json - using default 1")


# =========================================================================== SAVE FUNCTIES =====
def save_scores():
    save_json(SCORES_FILE, scores)

def save_current_round():
    save_json(CURRENT_ROUND_FILE, {'current_round': current_round})

def save_round_descriptions():
    save_json(ROUND_DESC_FILE, round_descriptions)

def save_jokers():
    save_json(JOKERS_FILE, jokers)

def save_correct_answers():
    save_json(CORRECT_ANSWERS_FILE, correct_answers)

def save_player_colors():
    save_json(PLAYER_COLORS_FILE, player_colors)

def save_led_brightness():
    save_json(LED_BRIGHTNESS_FILE, led_brightness)

def broadcast_brightness():
    r, g, b = led_brightness['r'], led_brightness['g'], led_brightness['b']
    mqtt_client.publish("quiz/all", f"brightness:{r},{g},{b}")

def save_config():
    save_json(CONFIG_FILE, {
        'answer_timeout': ANSWER_TIMEOUT,
        'total_rounds': TOTAL_ROUNDS,
        'questions_per_round': QUESTIONS_PER_ROUND,
        'language': config.get('language', 'nl')
    })

def load_jokers():
    global jokers
    jokers = load_json(JOKERS_FILE, {})

load_jokers()


# =========================================================================== FLASK APP =====
app = Flask(__name__)

@app.context_processor
def inject_lang():
    return {'t': lang_strings}


# =========================================================================== GLOBALS =====
registered = set()
presses = []
disabled = set()
latencies = []
last_heartbeat = {}
button_versions = {}
button_ips = {}
lock = threading.RLock()
OFFLINE_TIMEOUT = 15
answer_end_time = None
timer_thread = None
current_questions_completed = 0
current_question_started = False
current_question_has_winner = False
buzzer = OutputDevice(BUZZER_PIN)


# =========================================================================== HULPFUNCTIES =====
def buzz_quizmaster(duration=0.5):
    def buzz_thread():
        buzzer.on()
        time.sleep(duration)
        buzzer.off()
    threading.Thread(target=buzz_thread).start()

def get_current_answerer():
    for ts, id in presses:
        if id not in disabled:
            return id
    return None

def reset_timer():
    global answer_end_time, timer_thread
    answer_end_time = None
    if timer_thread and timer_thread.is_alive():
        timer_thread.join(timeout=1)
    timer_thread = None

def lock_buttons():
    mqtt_client.publish("quiz/all", "lock")

def unlock_buttons():
    mqtt_client.publish("quiz/all", "unlock")

def start_answer_timer():
    global answer_end_time, timer_thread
    if ANSWER_TIMEOUT == 0:
        print("Answer timer disabled (timeout = 0)")
        answer_end_time = None
        return
    print(f"Starting answer timer for {ANSWER_TIMEOUT} seconds")
    answer_end_time = time.time() + ANSWER_TIMEOUT
    def timer_func():
        time.sleep(ANSWER_TIMEOUT)
        with lock:
            if presses:
                print("Timeout reached - buzzing")
                buzz_quizmaster(1.5)
    timer_thread = threading.Thread(target=timer_func, daemon=True)
    timer_thread.start()

def process_presses():
    print("Processing presses called")
    with lock:
        current = get_current_answerer()
        if current:
            print(f"Current answerer found: {current} - buzzing and starting timer")
            mqtt_client.publish(f"quiz/{current}", "buzz", qos=1)
            buzz_quizmaster()
            start_answer_timer()
        else:
            print("No current answerer - timer not started")

def clear_round_state():
    """Reset presses, disabled and latencies."""
    with lock:
        presses.clear()
        disabled.clear()
        latencies.clear()


# =========================================================================== MQTT =====
def on_connect(client, userdata, flags, rc, properties=None):
    print("Connected to MQTT")
    client.subscribe("quiz/#")
    client.publish("quiz/all", "disable")
    broadcast_brightness()
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

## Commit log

2026-02-22 Initial commit: Quiz Buttons 2026
    ESP32-S3 (Seeed XIAO) firmware + Raspberry Pi Flask/MQTT quiz controller.
    Features: buzzer patterns, RGB LED states, HTTP OTA updates, joker system,
    round/question flow, score tracking, and web-based game management UI.
    [main.cpp, server.py]
2026-02-22 Add README with full project documentation
    Covers hardware wiring, software architecture, game flow, LED colors,
    buzzer patterns, MQTT topics, web interface, and setup instructions.
2026-03-01 Update firmware v0.8 and server v1.0.5 with new features and fixes
    - ESP32: add D2/GPIO3 status LED (solid=connected, flash=disconnected)
    - ESP32: fix rank color race condition (disable/lock respect rankActive flag)
    - Server: add player color support (setup + results table)
    - Server: fix press timestamps for speed column (Jinja2 scoping workaround)
    - Server: remove immediate disable broadcast on button press (fixes 2nd button LED)
    - Server: fix reset_scores to unlock buttons and clear round state
    - README: update wiring, LED reference, versions, and file structure
    [main.cpp, server.py]
2026-03-01 README: add resistor values to ESP32 wiring table
2026-03-01 README: add ESP32 power supply section (LiPo battery + TP4056 boost module)
2026-03-01 Add 3D printed enclosure files and document in README
    FreeCAD source + 5 printable parts (main body, top, bottom, battery bracket, battery support)
    [QuizButton2026-PartQB2026AccuBracket.3mf, QuizButton2026-PartQB2026AccuSupport.3mf, QuizButton2026-PartQB2026Bottom.3mf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]
2026-03-01 README: add battery and charger/boost module to components table
2026-03-01 Replace timeout dropdown with number input, support 0 to disable timeout
    - setup.html: free-entry number field (min=0) replaces fixed dropdown
    - server.py: start_answer_timer skips when ANSWER_TIMEOUT == 0
    [server.py]
2026-03-01 Firmware v0.9: force red LED on explicit disable, regardless of rankActive
    Individual disable (quiz/<id>) now clears rankActive and forces red immediately,
    so pressing 'Fout (Blokeren)' in the UI always turns the button red.
    Lock broadcast (quiz/all) still respects rankActive to preserve rank colors.
2026-03-01 reset_scores: lock buttons (red) instead of unlocking after reset
    Buttons stay red after reset until quizmaster presses 'Start Vraag',
    which explicitly enables them. Matches the same flow as next_question/increment_round.
    [server.py]
2026-03-01 Firmware v0.10: reset command triggers full ESP.restart()
    On receiving 'reset' via quiz/all, the button now performs a full reboot
    (short beep, then ESP.restart()) — identical to power-on boot sequence:
    green → red → white → blue + 1s beep.
    [main.cpp]
2026-03-01 README: add battery life calculations to power supply section
2026-03-01 Add per-channel RGB brightness control via setup.html sliders (firmware v0.13)
    - main.cpp: brightness R/G/B floats scale ledcWrite output; MQTT brightness:R,G,B handler
    - server.py: led_brightness persisted to JSON, /set_led_brightness route, broadcast on connect/reregister
    - setup.html: section 6 with three sliders (0-255) for R, G, B with live value display
2026-03-01 Update README: firmware v0.13, brightness feature, setup sections, rank colors
    - Firmware version example updated to v0.13
    - Game flow: rank 2 color Cyan → Purple
    - MQTT topics: add brightness:R,G,B to quiz/all payload
    - Setup page sections: section 6 = RGB LED brightness, section 7 = OTA
    - Section 1 timeout: free-entry (0 = disabled)
    - File structure: add led_brightness.json
    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
2026-03-01 Add GUI localization: NL/EN language files with Setup page toggle
    - New: raspberry_pi/lang/nl.json and lang/en.json with all UI strings
    - server.py: load_language(), context_processor injecting 't' dict,
    /set_language route, save_config() persists language choice
    - All 4 templates converted to {{ t.section.key }} references
    - setup.html: new section 0 with language dropdown (NL / EN)
    - results.html: JS countdown string localized via LANG_TIME_LEFT constant
    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
2026-03-01 Add player manuals (NL + EN) and HTML manual page at /manual
    - SPELER_HANDLEIDING.md: Dutch player manual (Markdown, printable)
    - PLAYER_MANUAL.md: English player manual (Markdown, printable)
    - templates/manual.html: HTML page served at /manual with NL/EN
    toggle, colored LED dots, styled tables and tip boxes
    - server.py: /manual route, lang query param defaults to server language
